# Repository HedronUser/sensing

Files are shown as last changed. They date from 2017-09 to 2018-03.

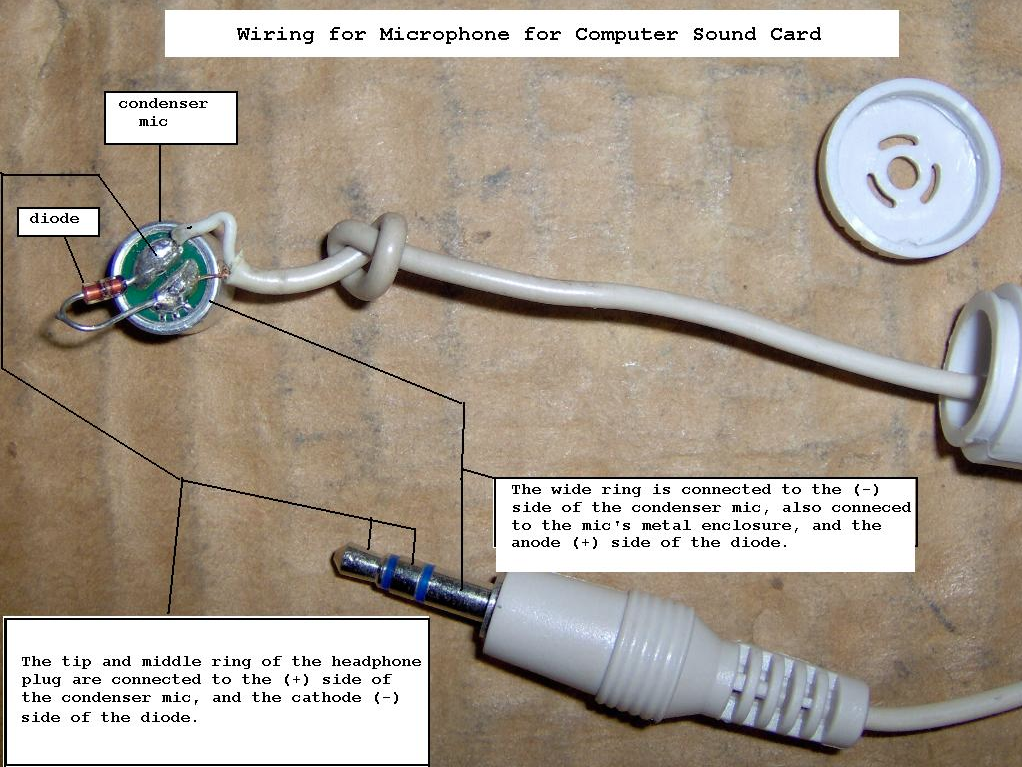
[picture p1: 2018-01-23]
docs/microphone jack pic.png

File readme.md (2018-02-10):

# sensing kits

Made for/with the [PNCA Sensing the Environment Project](http://pnca.edu/makethinkcode/news/c/sensing_the_environment).

This is a sound recording and reporting kit. Right now, sound is recorded to an onboard SD card. 
Stage 1 will send this info over Wifi to a Python server on a host computer.

## objectives
- record bird songs at night for as long as possible (1-2weeks)
- transmit bird songs to cloud server after recording is finished (during the day)
- connect to cloud server to download recorded data
- make a recording device that is cheap and easy to setup and maintain

## software

For the Rpi:
- Image of RPi_sensing (TODO: make and post image of pi with everything configured proper) 

For the computer:
- Python 2.*
- Virtualenv & virtualenvwrapper
- [pip](https://pip.pypa.io/en/stable/)

## software overview

- a python script takes care of sending files to ftp server on a schedule
- a built-in linux program called arecord takes care of recording data on a schedule
- a shell script takes care of recording intervals and generating Pi-specific (using MAC address) filenames
- witty pi software and hardware takes care of sleep/wake schedules

## hardware

You will need:
-[Raspberry Pi 3 model B]
-[Sabrent USB sound card adapter]
-[Sparkfun Sound Detector or Adafruit Amplifier]
-[Witty Pi 2 Cape for Rpi]
-[microSD card (8GB is fine)]
-[USB thumb drive (128GB)]
-[Waterproof enclosure ]
-[small waterproof gland (for microphone) PG7]
-[medium waterproof gland (for AC power) PG9]
-[Minimum 2.1A 5VDC power supply]
-[AC extension cord]
-[shielded microphone cable ]

Optional accessories :
-[HDMI cable],
-[HDMI monitor],
-[USB keyboard]
-[USB mouse]
- [Wireless dongle w/ removable 5dB antennae that works with Pi(optional) (enhancement for larger range)]
-[Hardware for standoffs]
-[acrylic sheets for mounting plate (enclosure)]

## hardware overview

An SFTP server installed on an Intel Nuc  will live at Dylan's place  

An SFTP client install on the Rpi lives in the field

## Installation of USB audio device and Arecord

On the raspberry pi, follow the setup on [raspberry pi audio setup](http://www.g7smy.co.uk/2013/08/recording-sound-on-the-raspberry-pi/) 

then test recording with:

arecord -f S16_LE --r=22000 -D plughw:1 --max-file-time 30 --duration=10 -vv ~/rectest11.wav
 
## configuration of pi

the witty pi software uses a script to control when to go to sleep and wake up found in 
/wittypi/schedules/

edit the etsyhost name to be unique:

1. sudo nano /etc/hosts

## configuration of arecord

duration is the maximum length of chunks in seconds

max file time is the ultimate length of recording in seconds

## using a virtual environment

On the host computer, in the project directory, run the following commands to set up your Python environment:

```
mkvirtualenv sensing
pip install -r requirements.txt
```

This should install `pyserial` locally in your `sensing` virtual environment.

run `brew install sox` to get SoX on your computer.

### virtualenvs

To work in your virtualenv, run the command `workon sensing`. To leave, run `deactivate`.

## project structure

- `/teensy` stores Teensy sketches for microcontroller based sensing module (legacy)
- `/RPi` will store "base station code"; i.e., the client with the microphone sensing unit that reports data back to server and a basic frontend to confirm that communication is working.
- `/raspberry_pi` will store "base station code"; i.e., the client with the microphone sensing unit that reports data back to server and a basic frontend to confirm that communication is working.
- `/docs` a place to store all documentation for this project 
- `/enclosure` a place to store all things enclosure related - design files for 3d printing and laser cutting 

## development
Slack
- Hackathon: Sensing the Environment
- Workspace URL: sensingtheenvironment.slack.com 

## building from source
- download latest version of NOOBs or Debian Jessie/Wheezy 
- update software 
- configure keyboard, locale, and timezone as US.
- clone this repo 
- run python script as a bash script on startup
- follow [raspberry pi audio setup](http://www.g7smy.co.uk/2013/08/recording-sound-on-the-raspberry-pi/) to make sure you can record with your setup

## references
- [microphone jack schematic](https://electronics.stackexchange.com/questions/307430/confusion-about-trrs-jack-and-mic-input)
- [microphone jack pic](https://cdn.instructables.com/ORIG/FHZ/YTV8/GAPUWXXX/FHZYTV8GAPUWXXX.jpg)
- [raspberry pi audio setup](http://www.g7smy.co.uk/2013/08/recording-sound-on-the-raspberry-pi/)

## credits
Nandini
Violet Pena
Trace Harris
Richard
Dylan Mcnamee
Chris Eykamp
Candace Hazelwood
Jesse Jenkins
Daniel Tiebel

## troublehsooting known bugs

- raspberry pi gives error : could not get clock with witty pi installed

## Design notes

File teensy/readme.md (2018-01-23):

# sensing kits

Made for/with the [PNCA Sensing the Environment Project](http://pnca.edu/makethinkcode/news/c/sensing_the_environment).

This is a sound recording and reporting kit. Right now, sound is recorded to an onboard SD card. Stage 0 will send this info over USB Serial to a Python server on a host computer.

## software

For the Teensy:
- [Arduino IDE](https://www.arduino.cc/en/Main/Software) for writing and uploading sketches
- [Teensyduino](https://www.pjrc.com/teensy/teensyduino.html) for Arduino to work with Teensy boards
- [SoX](http://sox.sourceforge.net/) to convert audio. Recommend installing via Homebrew (`brew install sox`)

For the computer:
- Python 2.*
- Virtualenv & virtualenvwrapper
- [pip](https://pip.pypa.io/en/stable/)

## hardware

You will need:
- Teensy 3.2
- Teensy Audio Shield (TODO: part number)
- SparkFun mic (TODO: part number)
- microSD card (ours is 8GB)
- USB --> MicroUSB cable for connecting Teensy to computer
- SD card adaptor so microSD card can be read on computer
- OPTIONAL: ESP8266 WiFi module

## installation

On the host computer, in the project directory, run the following commands to set up your Python environment:

```
mkvirtualenv sensing
pip install -r requirements.txt
```

This should install `pyserial` locally in your `sensing` virtual environment.

run `brew install sox` to get SoX on your computer.

You may need to install additional packages in your Arduino environment in order to interface with a Teensy (TODO: document this).

### virtualenvs

To work in your virtualenv, run the command `workon sensing`. To leave, run `deactivate`.

## project structure

- `/teensy` stores Teensy sketches
- `/base` will store "base station code"; i.e., the server the sensing unit reports data back to and a basic frontend to confirm that communication is working.
- `/rawToWav.sh` uses SoX to convert .RAW audio files, as they are saved to the SD card, into .WAV files. Run it via `source rawToWav.sh path/to/file/without/extension`

## fun facts
- our SD card uses [8.3 filenames](https://en.wikipedia.org/wiki/8.3_filename), so all files saved there can have names of max 8 characters, not including directory names or extension. The extension can be a max of 3 characters.

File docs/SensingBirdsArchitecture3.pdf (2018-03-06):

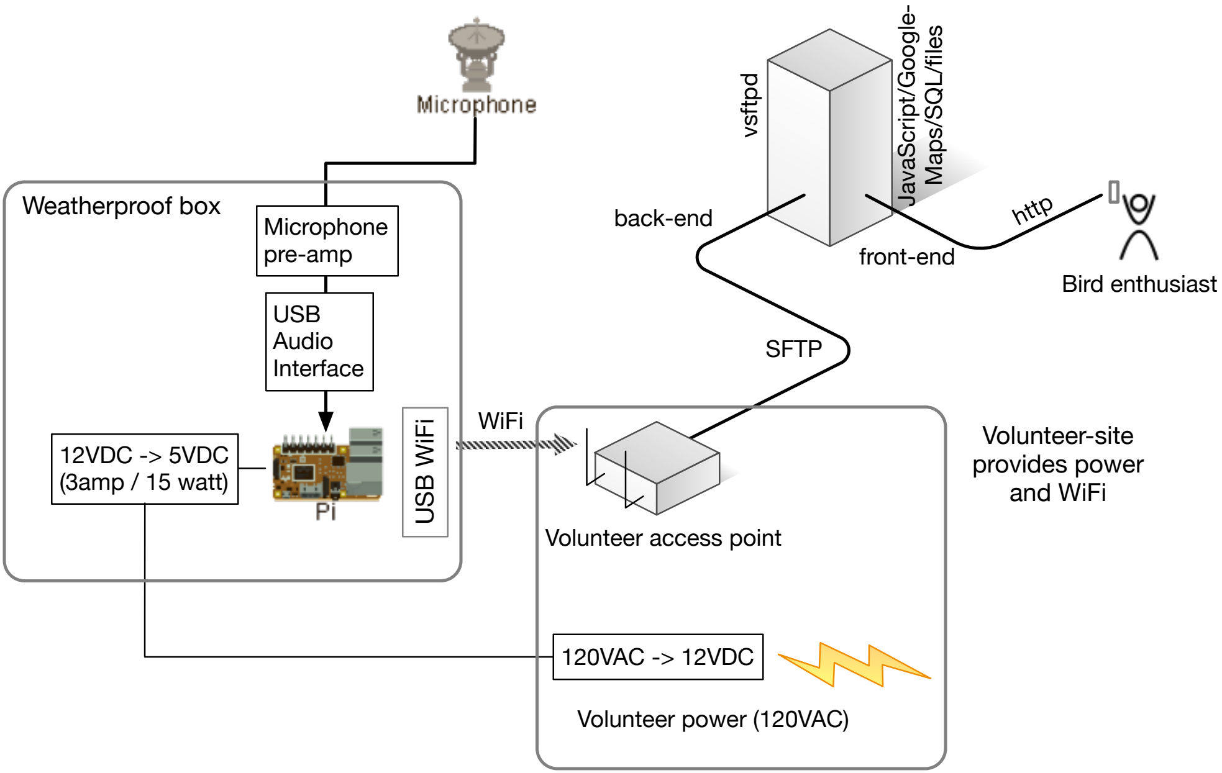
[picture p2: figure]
Bird enthusiast; USB Audio Interface; Volunteer access point; WiFi; SFTP; http; vsftpd; JavaScript/Google- Maps/SQL/files; back-end; front-end; Microphone pre-amp; USB WiFi; 120VAC -> 12VDC; 12VDC -> 5VDC (3amp / 15 watt); Volunteer power (120VAC); Weatherproof box; Volunteer-site provides power and WiFi

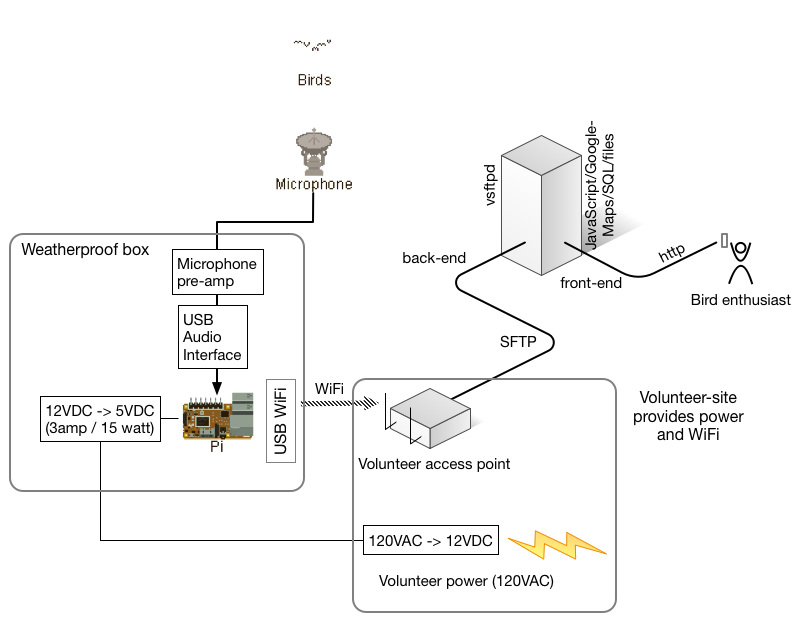
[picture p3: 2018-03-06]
docs/SensingBirdsArchitecture3.png

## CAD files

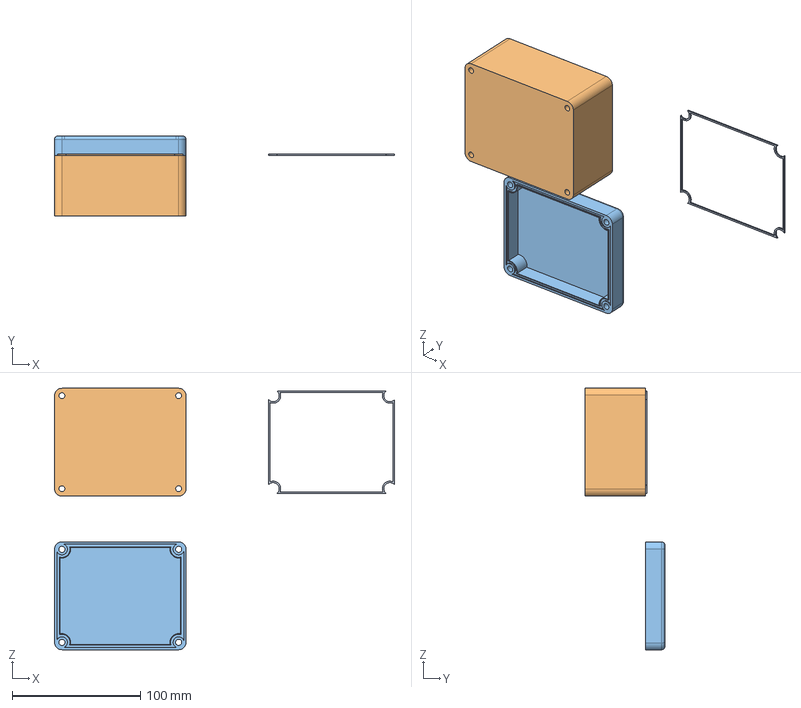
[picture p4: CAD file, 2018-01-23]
Enclosure/STEP/Sensing_enclosure v4.step
265.6 x 62.4 x 204.2 mm

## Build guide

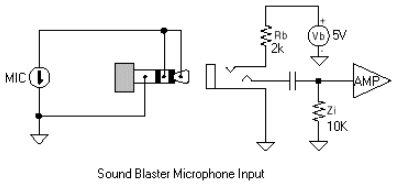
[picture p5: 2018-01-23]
docs/microphone jack wiring.png

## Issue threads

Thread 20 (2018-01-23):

Reboot on a schedule

HedronUser, 2018-01-23:
Tell Pi to reboot every couple days just to destroy any chance of memory leaks and stack/heap overflows.

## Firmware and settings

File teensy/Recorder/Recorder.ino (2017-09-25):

#include <Time.h>
//#include <TimeLib.h>
#include <TimeAlarms.h>

// Record sound as raw data to a SD card, and play it back.
//
// Requires the audio shield:
//   http://www.pjrc.com/store/teensy3_audio.html
//
// Three pushbuttons need to be connected:
//   Record Button: pin 0 to GND
//   Stop Button:   pin 1 to GND
//   Play Button:   pin 2 to GND
//
// This example code is in the public domain.

#include <Arduino.h>
#include <Bounce.h>
#include <Audio.h>
#include <Wire.h>
#include <SPI.h>
#include <SD.h>
#include <SerialFlash.h>
#include <TimeLib.h>

// GUItool: begin automatically generated code
AudioInputI2S            i2s2;           //xy=105,63
AudioAnalyzePeak         peak1;          //xy=278,108
AudioRecordQueue         queue1;         //xy=281,63
AudioPlaySdRaw           playRaw1;       //xy=302,157
AudioOutputI2S           i2s1;           //xy=470,120
AudioConnection          patchCord1(i2s2, 0, queue1, 0);
AudioConnection          patchCord2(i2s2, 0, peak1, 0);
AudioConnection          patchCord3(playRaw1, 0, i2s1, 0);
AudioConnection          patchCord4(playRaw1, 0, i2s1, 1);
AudioControlSGTL5000     sgtl5000_1;     //xy=265,212
// GUItool: end automatically generated code

const int myInput = AUDIO_INPUT_MIC;
bool ended = false;
// Use these with the Teensy Audio Shield
#define SDCARD_CS_PIN    10
#define SDCARD_MOSI_PIN  7
#define SDCARD_SCK_PIN   14

// The file where data is recorded
File frec;


void setup() {

    
  setTime(17,26,0,20,9,17); // set time to 5:26:00pm September 20th 2017
  
  timeStatus();
  while(1){
    char filename[12];
    
    getfilename(filename);
    Serial.println();

    Serial.print(filename);
    delay(1000);
  }
  // create the alarms 
  Alarm.alarmRepeat(6,45,0, MorningAlarm);  // 6:45am every day
  Alarm.alarmRepeat(17,45,0,EveningAlarm);  // 5:45pm every day 
  
  AudioMemory(60);
  Serial.begin(9600);
  // Enable the audio shield, select input, and enable output
  sgtl5000_1.enable();
  sgtl5000_1.inputSelect(myInput);
  sgtl5000_1.volume(0.5);

  // Initialize the SD card
  SPI.setMOSI(SDCARD_MOSI_PIN);
  SPI.setSCK(SDCARD_SCK_PIN);
  if (!(SD.begin(SDCARD_CS_PIN))) {
    // stop here if no SD card, but print a message
    while (1) {
      Serial.println("Unable to access the SD card");
      delay(500);
    }
//  } else {
//    delay(1000);
  }
  printDirectory(frec, 0); //this runs once at beginning to list all files and directories on SD card.

  startRecording();
}

#define TIME_HEADER "T"
int loopNumber = 0;

//global to store recording state  - initialize variable off - false indicates teensy shouldn't be recording
bool recordFlag = true; 

//initialize recording status on 
int recordingStatus = 1; 

//initilize track counting variable (this should be about 12 tracks per day)
int trackcount = 0;

void loop() {

  Alarm.delay(0); // needed for alarm function to check alarms

//  Serial.println(now());
//  unsigned long myTime = 0L;
//  const unsigned long DEFAULT_TIME = 1357041600;

//  if (Serial.find(TIME_HEADER)) {
//    myTime = Serial.parseInt();
//    Serial.println(myTime);
//  }


  if (!frec) {
   return;
  }
  
  int time = millis();
  int length = 10 * 1000; //specifies the time of recording - 1 hr.

if (recordFlag) {
  if (time % length == 0) {
    trackcount++;
    stopRecording();
    loopNumber++;
    startRecording();
  } else {
    continueRecording();
  }

} else if (recordingStatus == 1){ // this should end any recordings that were stopped in the middle of alarm cleanly and also prevent recordings from happening when teensy is initialized in the daytime
  stopRecording();
  }



  
//  if (time < 10000) {
//    continueRecording();
//  } else if (ended == false) {
//    ended = true;
//    stopRecording();
//  }
}

void getfilename(char *fname) { //points to global filename array
  //returns an unsigned int - format YYMMDDHH.RAW 
   Serial.print("getfilename");
   int h = hour();
      Serial.print(" h =");

   Serial.print(h);
   int y = year() % 100;
         Serial.print(" y =");

   Serial.print(y);

   int d = day();
//   if (d < 10){
//    d = 
//   }
         Serial.print(" d =");

      Serial.print(d);

   int m = month();
         Serial.print(" m =");

   Serial.print(m);
      fname[0] = (y / 10) + '0' ; //single quotes adding to a char , gives a  number between 0 - 9
      fname[1] = (y % 10) + '0'; //
      fname[2] = (m / 10) + '0' ; //single quotes adding to a char , gives a  number between 0 - 9
      fname[3] = (m % 10) + '0'; //
      fname[4] = (d / 10) + '0' ; //single quotes adding to a char , gives a  number between 0 - 9
      fname[5] = (d % 10) + '0'; //
      fname[6] = (h / 10) + '0' ; //single quotes adding to a char , gives a  number between 0 - 9
      fname[7] = (h % 10) + '0'; //
      fname[8] = '.';
      fname[9] = 'R';
      fname[10] = 'A';
      fname[11] = 'W';
      fname[12] = 0; //null terminator
      Serial.print("   ");
   Serial.print(fname);
   Serial.println();

}

void startRecording() {
  Serial.println('a');
  //need to change filename to be based on date - it cannot exceed 8 characters plus extension, it should take the format HH/DD/MM/YY
  //I think my approach will be to call a filename function that assembles a new file name and returns it as a string.
  //char myfilename[12];
  //snprintf(myfilename, 13, "%s.RAW", String(loopNumber).c_str());
  char filename[9];
  //snprintf(getfilename(), 8, "%s.RAW", getfilename());
  Serial.println(filename);

//  if (SD.exists(filename)) {
//    // The SD library writes new data to the end of the
//    // file, so to start a new recording, the old file
//    // must be deleted before new data is written.
//    SD.remove(filename);
//  }
//  int num = random();
//  int num = Teensy3Clock.get();
//  int num = now();
//  Serial.println(String(num) + ".RAW");
//  Serial.println(month());
//  randomSeed(analogRead(13));
//  Serial.println(year());
//  const char *truncated = String(random()).substring(0, 8).c_str();
  Serial.println(filename);
  frec = SD.open(filename, FILE_WRITE);
  
  Serial.println(frec);
  if (frec) {
    queue1.begin();
//    TODO: log file name, begin/end time
  } else {
    Serial.println("File creation failed :(");
  }
}

void continueRecording() {
  if (queue1.available() >= 2) {
    byte buffer[512];
    // Fetch 2 blocks from the audio library and copy
    // into a 512 byte buffer.  The Arduino SD library
    // is most efficient when full 512 byte sector size
    // writes are used.
    memcpy(buffer, queue1.readBuffer(), 256);
    queue1.freeBuffer();
    memcpy(buffer+256, queue1.readBuffer(), 256);
    queue1.freeBuffer();
    // write all 512 bytes to the SD card
//    elapsedMicros usec = 0;
    frec.write(buffer, 512);
    // Uncomment these lines to see how long SD writes
    // are taking.  A pair of audio blocks arrives every
    // 5802 microseconds, so hopefully most of the writes
    // take well under 5802 us.  Some will take more, as
    // the SD library also must write to the FAT tables
    // and the SD card controller manages media erase and
    // wear leveling.  The queue1 object can buffer
    // approximately 301700 us of audio, to allow time
    // for occasional high SD card latency, as long as
    // the average write time is under 5802 us.
//    Serial.print("SD write, us=");
//    Serial.println(usec);
  }
}

void stopRecording() {
//  Serial.println(String(random()) + ".RAW");
  queue1.end();
//  if (mode == 1) {
    while (queue1.available() > 0) {
      frec.write((byte*)queue1.readBuffer(), 256);
      queue1.freeBuffer();
    }
    frec.close();
    Serial.println("End recording");
    recordingStatus = 0;
//  }
//  mode = 0;
}

void adjustMicLevel() {
  // TODO: read the peak1 object and adjust sgtl5000_1.micGain()
  // if anyone gets this working, please submit a github pull request :-)
}

void printDirectory(File dir, int numTabs) {
  while (true) {

    File entry =  dir.openNextFile();
    if (! entry) {
      // no more files
      break;
    }
    for (uint8_t i = 0; i < numTabs; i++) {
      Serial.print('\t');
    }
    Serial.print(entry.name());
    if (entry.isDirectory()) {
      Serial.println("/");
      printDirectory(entry, numTabs + 1);
    } else {
      // files have sizes, directories do not
      Serial.print("\t\t");
      Serial.println(entry.size(), DEC);
    }
    entry.close();
  }
}


// functions to be called when an alarm triggers:
void MorningAlarm(){
  Serial.println("Alarm: - turn recording off");
  recordFlag = false; //this turns off the recording
  Serial.println("Alarm: - sleep Teensy");    
}
void EveningAlarm(){
  Serial.println("Alarm: - turn recording on");
  recordFlag = true; //this turns on the recording
  Serial.println("Alarm: - wake Teensy");             
}

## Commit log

2017-09-25 added timestamp and timealarm libraries/modules, teensy records 12 hours per pay, also the filename is getting set to the date format YYMMDDHH.RAW
2018-01-23 added design file for current enclosure. This needs to be enlarged to fit the new USB audio adapter. Updated readme as well.
    [Sensing_enclosure v4.step]
2018-02-06 added some recordings with and without the parabolic dish. I did some basic frequency analysis and volume comparison stuff with Audacity. I'll attach those screen shots and the text file about the fi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
2018-02-06 Attached the notes to make sense of the attached screenshots and audio files. Also took pictures of the setup.
